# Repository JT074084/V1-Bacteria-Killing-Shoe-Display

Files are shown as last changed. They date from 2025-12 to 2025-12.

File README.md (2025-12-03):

# V1 Bacteria Killing Shoe Display

These are all the files for V1 of the Bacteria Killing Shoe Display.

Keep in mind, I had pieced together the main ESP32 code from bits of code that either I or an LLM had written in the past, so if anything looks off/messy, that's probably why.

I apologize for the lack of a schematic/wiring diagram for this. Unfortunately, I was figuring out where everything should go as I was programming it, and I didn't really write anything down.

In the video, I didn't really get into the specifics of how everything fit together, but if you do decide to build this, I have included a "problems and pictures" doc. This document has a list of the different problems that V1 has, along with pictures to help show how things fit together.

Now, if you don't want to build this but saw some sort of component you liked, I've also included a "materials list" doc, which has all of the different parts I used, along with links to where you can get them.

Anyway, thank you for watching the video! I hope you enjoyed it! I have some ideas for a V2 that should be way cooler than this, but we'll have to see what happens next.

## Licenses

| Content | License | What This Means |
|---|---|---|
| **Code** (`V1_Shoe_Display.ino`, `debug_ui.py`) | **[MIT License](LICENSE)** | Free to use, modify, sell — just keep my copyright |
| **3D Models** (`.stl`) | **[CC BY-SA 4.0](LICENSE-3D.txt)** | Free to print, remix, sell — **must credit me** + share remixes under same license |
| **PDF Docs** (`*.pdf`) | Same as **3D models** → **CC BY-SA 4.0** | Diagrams, photos, and text are part of the design |

**Copyright © 2025 JT074084**

*JT074084*

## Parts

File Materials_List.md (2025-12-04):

V1 Shoe Display Materials List:
JLCMC Parts
Linear Actuator: https://jlcmc.com/product/s/B16/BQD-JKK60B/steel-linear-actuators-kk-series-motor-side-installation-60mm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 | Part Number: JKK60B-5-P-300-A2-LM-L-57-C 
Cooling and Chlorine Dioxide Fans: https://jlcmc.com/product/b/I08/BR5690/fa-%E5%B7%A5%E4%B8%9A%E6%8E%A7%E5%88%B6-%E4%BD%8E%E5%8E%8B%E9%85%8D%E7%94%B5-%E7%94%B5%E6%B0%94%E8%BE%85%E6%9D%90-%E9%A3%8E%E6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 | Part Number: INAF-80
Drag Chain End Links: https://jlcmc.com/product/s/B11/BKTJ/fa-%E7%9B%B4%E7%BA%BF%E8%BF%90%E5%8A%A8%E9%9B%B6%E4%BB%B6-%E6%8B%96%E9%93%BE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 | Part Number: BKTJ-F20
Drag Chain Middle Links: https://jlcmc.com/product/s/B11/BKLJ/cable-carrier-15-series-bridge-type-non-openable | Part Number: BKLJ-F20-R28-N30-BKTJ 
DRAG CHAIN NOTE: When I bought the drag chain for this project, I accidentally only selected the end links. To avoid the delivery wait, I actually ended up 3d printing the middle ones (I have the files for that in my STL files folder), but I noticed the 3d printed ones were pretty weak. So I found the middle links on JLCMC, and I recommend you use those. They’ll be of much higher quality than standard FDM printed ones.
2020A Aluminium Rail: https://jlcmc.com/product/s/T01/TXCJ/extruded-aluminum-t-slot-20-series(eu) | Part Number: TXCJ-H6-2020A-L200 (Note: You would need around 152mm of this stuff for the connection areas, but 200mm should definitely cover miscuts and stuff.)
2040 Aluminium Rail: https://jlcmc.com/product/s/T01/TXCJ/extruded-aluminum-t-slot-20-series(eu) | Part Number: TXCJ-H7-2040-L400 (Note: You need around 348mm of this for the shoe bed, but this should give you an extra 50mm.)
ALUMINIUM RAIL NOTE: I originally got my rail off of an old Ender 3 3D printer I had, but these should be the same size.

Other Parts
PETG | Main Print Material: https://a.co/d/eFtnlSz (Note: I think it took around four 1kg rolls to make this.)
PETG | Door Print Material: https://a.co/d/3wo1hnw  (Note: I think it took one 1kg roll to make the shell for the door.)
TPU | Spring Material: https://a.co/d/5l1x0uM 
Power Supply: https://a.co/d/cfOMF5U 
Power Cable for Power Supply: https://a.co/d/dL7Kbja  
On/Off Switch Module for Power Supply: https://a.co/d/ajjtZjK  
Buck Converters: https://a.co/d/91aooBY  
Breadboards: https://a.co/d/bN8AEsD  
ESP-32: https://a.co/d/5vCUf5K  
Resistors: https://a.co/d/iCSJfpk  
Diodes: https://a.co/d/8zumlme 
Display RGB LEDs: https://a.co/d/b015BdR 
Buttons: https://a.co/d/9Ch9rfy 
Bearings: https://a.co/d/3fU0wwJ 
Servo: https://a.co/d/btITpLg
Stepper Motor: https://a.co/d/cRLKZDN 
Stepper Motor Driver: https://a.co/d/aeNL8AM 
Copper Tape: https://a.co/d/1QdixYN 
Glue: https://a.co/d/4SLxNcS 
Spiral Cable Wrap: https://a.co/d/axzYKvL (Note: I didn’t get mine off of Amazon, and I can’t remember the size, but it looks to be around ⅛”, so I hope this works.)
24 Gauge Wire: https://a.co/d/i1DXdUt 
Limit Switches: https://a.co/d/89OjKXr 
Easy Wire Connectors: https://a.co/d/7c76Mut (Note: These are supposed to be for cars or boats, but I found they worked pretty great for connecting things that needed to be disconnected often, like the fans.)
Sponges for Chlorine Dioxide: https://www.homedepot.com/p/HDX-All-Purpose-Easy-Eraser-Sponge-6-Sponges-HDX-6pk-Orig/307833221 
Chlorine Dioxide Tablets: https://a.co/d/70uV1f7 (Note: Be careful with these! I had the solution set out in the open for a few days before I put it in the shoe display.)
Carbon Fiber Rods: https://a.co/d/fpbQZGR 
UVC LEDs: https://www.lcsc.com/product-detail/C688875.html

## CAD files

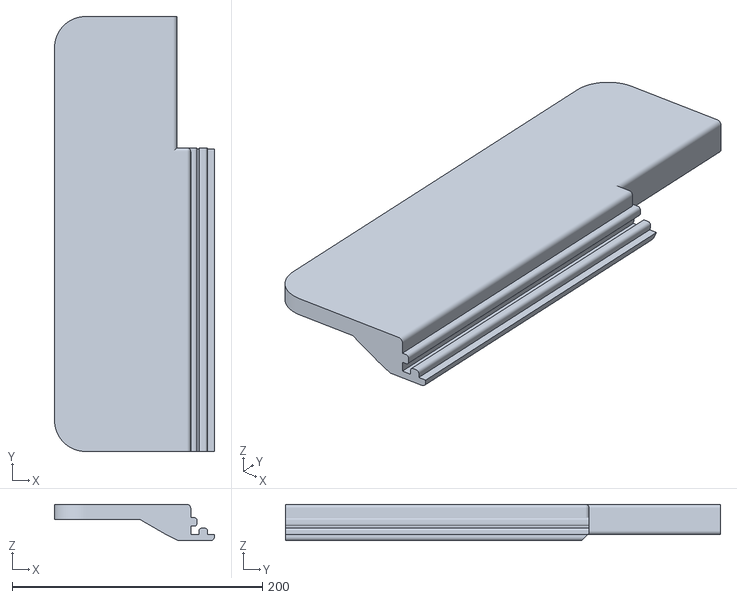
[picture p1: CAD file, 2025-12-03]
STL FILES/Shoe Bed Stuff/Bed Parts/V1 FINAL - Left Bed - Main.stl
128.0 x 348.0 x 29.0

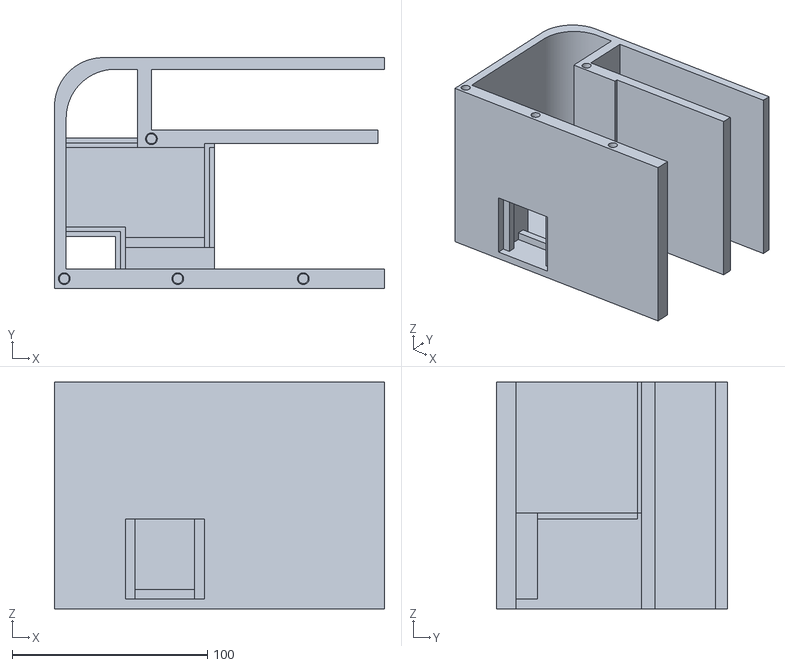
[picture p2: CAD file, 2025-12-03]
STL FILES/Base Stuff/Left Side Top Half/Left Side Main.stl
168.9 x 118.1 x 116.0

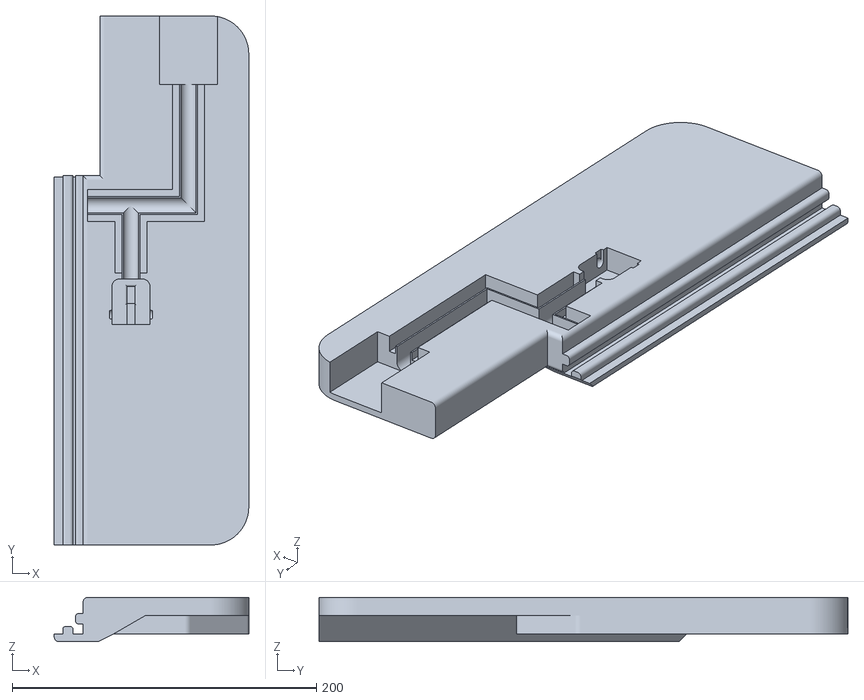
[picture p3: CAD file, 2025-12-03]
STL FILES/Shoe Bed Stuff/Bed Parts/V1 FINAL - Right Bed - Main.stl
128.0 x 348.0 x 29.0

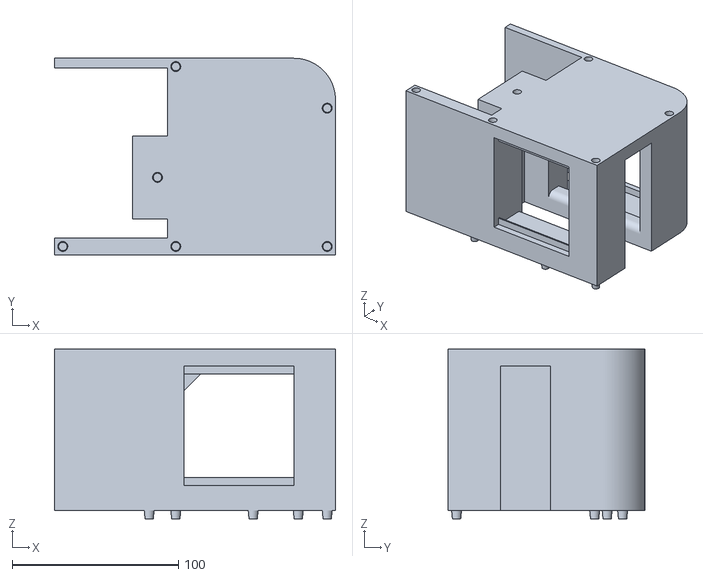
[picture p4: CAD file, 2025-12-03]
STL FILES/Base Stuff/Push Latch Mechanism Side/PLM Middle Main.stl
168.9 x 118.1 x 102.0

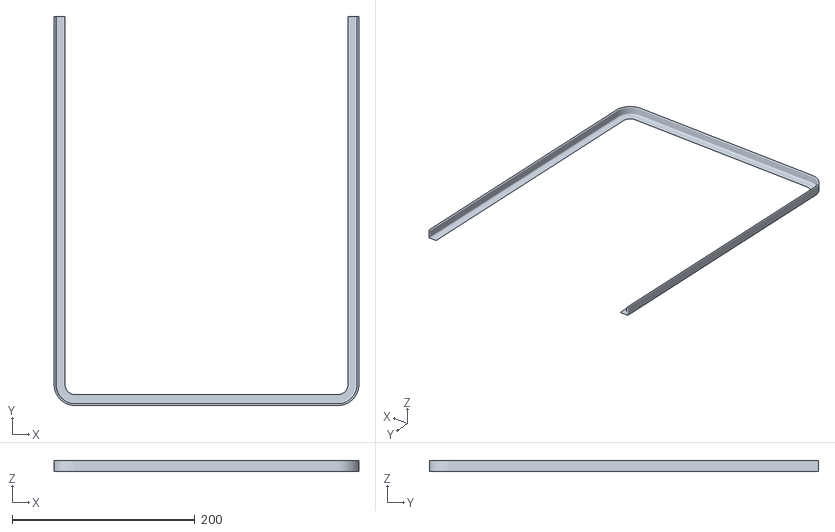
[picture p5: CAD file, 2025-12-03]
STL FILES/Base Stuff/LED Bar and Base Covers/V1 FINAL - LED Disperser.stl
333.8 x 426.0 x 12.0

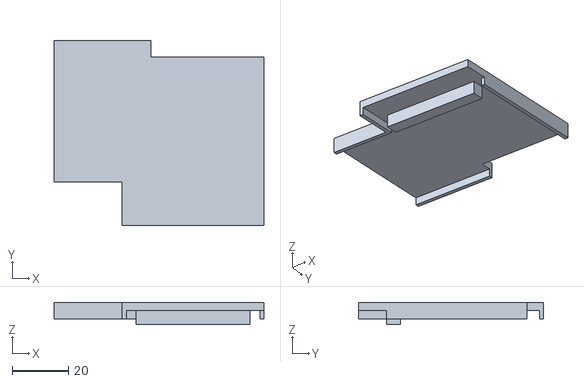
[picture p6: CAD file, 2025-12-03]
STL FILES/Base Stuff/Left Side Top Half/Left Side Air Duct Roof.stl
74.8 x 66.0 x 8.00

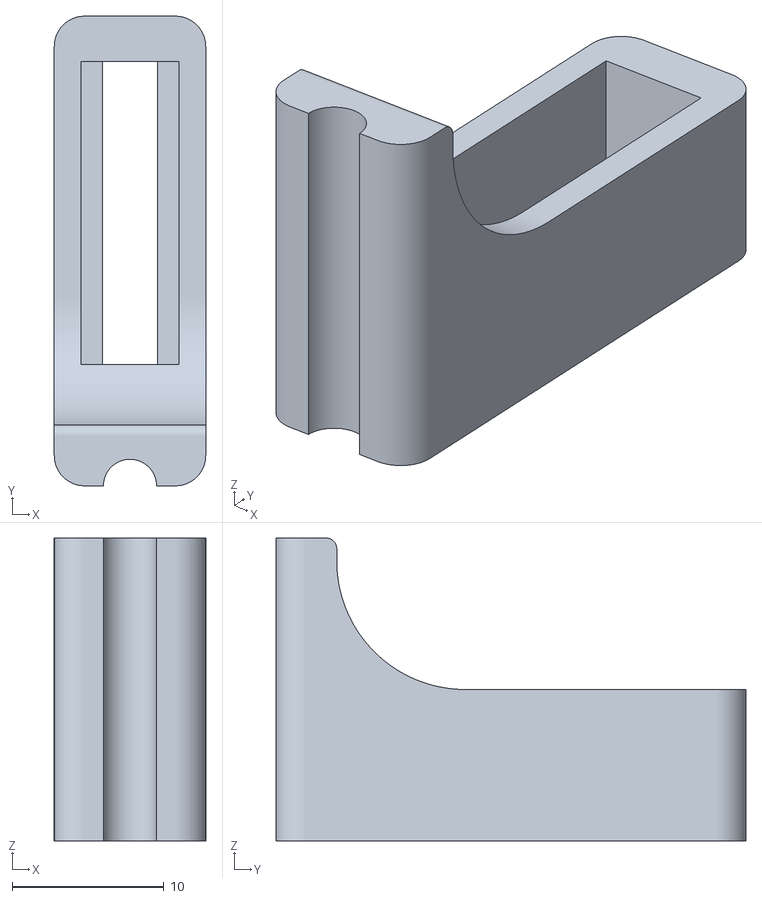
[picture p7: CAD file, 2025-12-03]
STL FILES/Base Stuff/Linear Actuator Stuff/Limit Switches/Limit Switch Case.stl
10.0 x 31.0 x 20.0

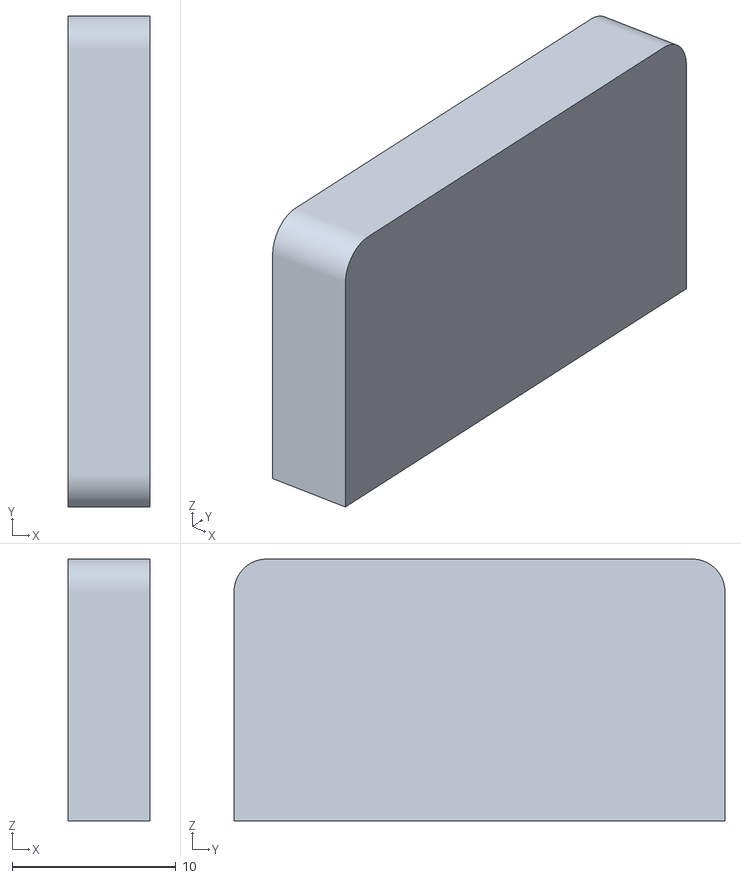
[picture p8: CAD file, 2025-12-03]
STL FILES/Base Stuff/Linear Actuator Stuff/Spacers/V1 FINAL - LAS 7.stl
5.00 x 30.0 x 16.0

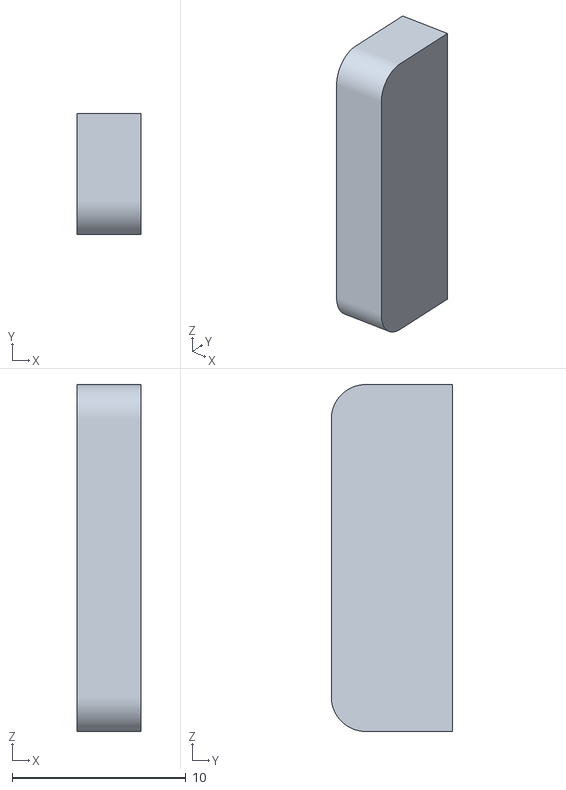
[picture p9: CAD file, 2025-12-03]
STL FILES/Base Stuff/Open:Close Button Stuff/V1 FINAL - Left Button Rail Cover.stl
3.70 x 7.00 x 20.0

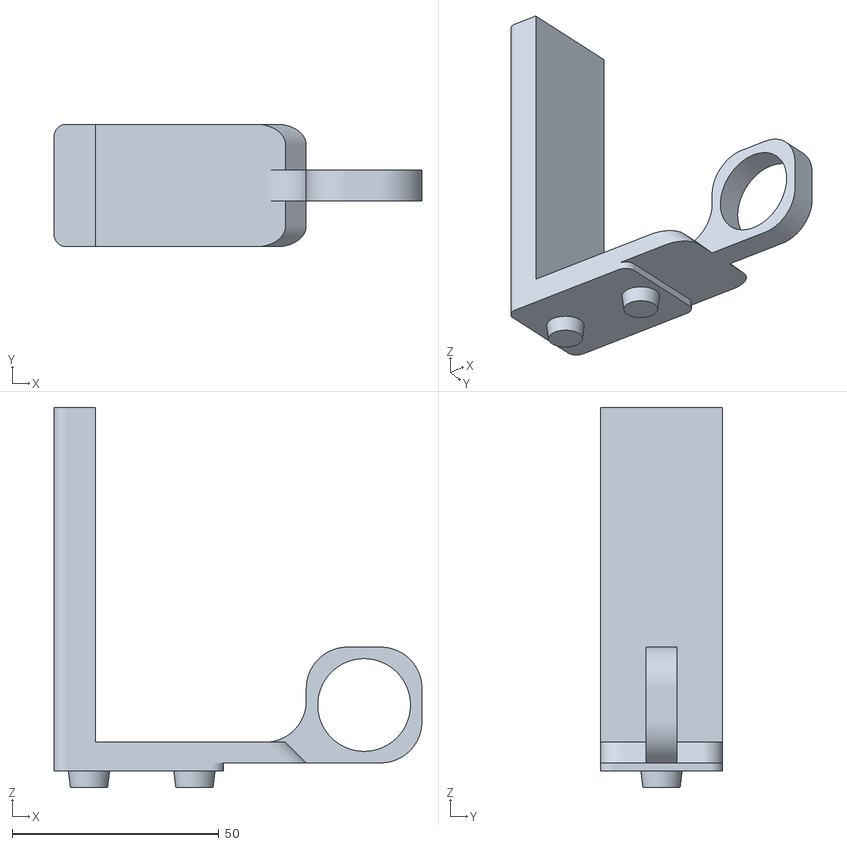
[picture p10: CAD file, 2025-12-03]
STL FILES/Base Stuff/Push Latch Mechanism Side/PLM Container Shelf.stl
89.0 x 29.6 x 92.0

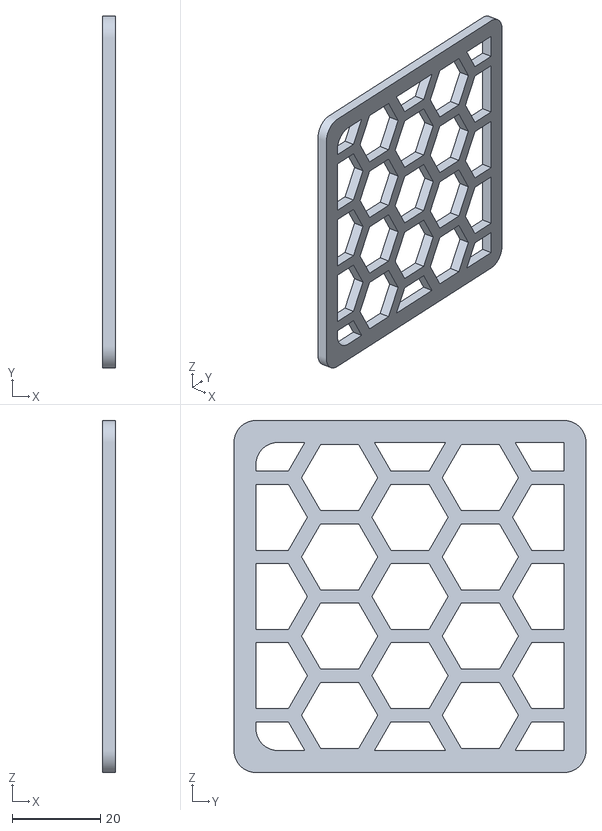
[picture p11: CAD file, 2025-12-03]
STL FILES/Base Stuff/V1 FINAL - Electronics Cooling Fan Guard.stl
3.00 x 80.0 x 80.0

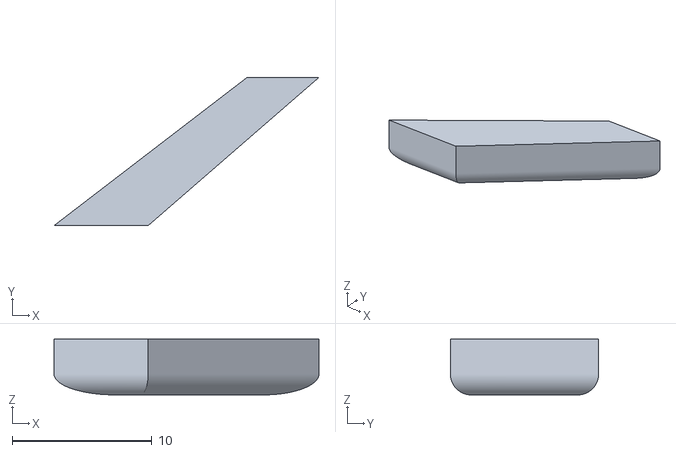
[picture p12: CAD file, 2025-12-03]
STL FILES/Door Stuff/Door Arm Stuff/Arm Connecting Pieces/Logo/V1 FINAL - Logo 4.stl
19.0 x 10.6 x 4.00

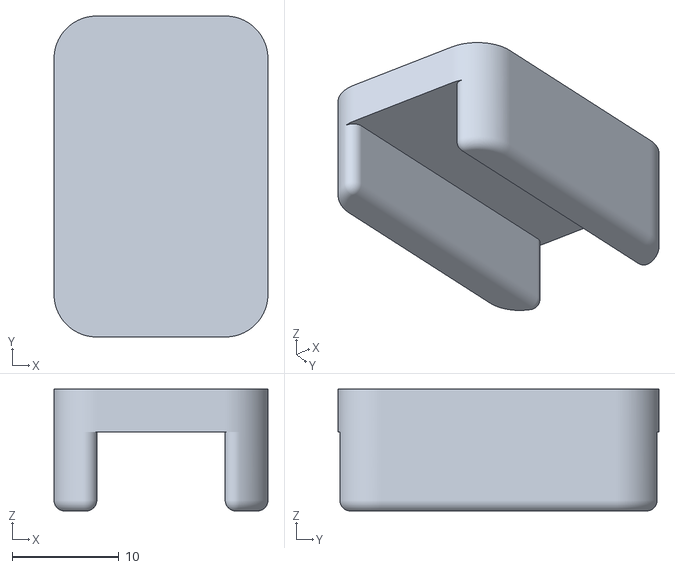
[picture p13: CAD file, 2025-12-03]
STL FILES/Door Stuff/Door Arm Stuff/Arm Connecting Pieces/V1 FINAL - ARM LT.stl
20.0 x 30.0 x 11.4

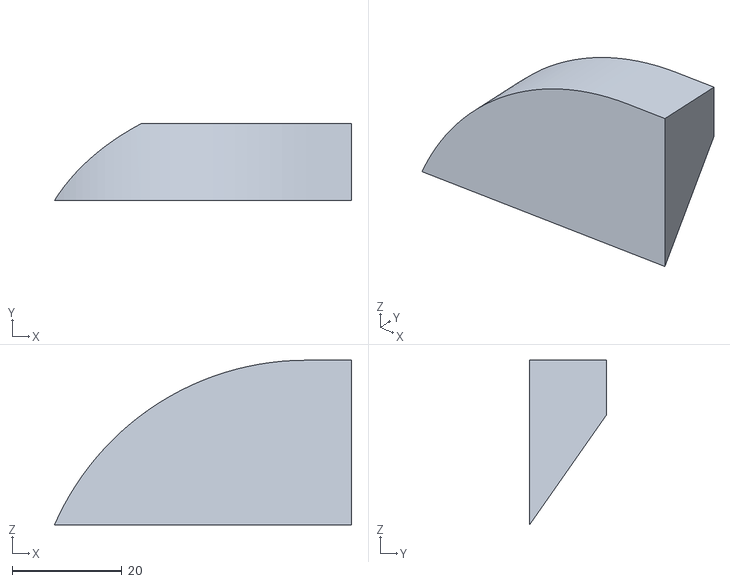
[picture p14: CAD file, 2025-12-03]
STL FILES/Door Stuff/Door Arm Stuff/V1 FINAL - Bearing Case Spacer Left.stl
54.1 x 14.0 x 30.0

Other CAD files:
STL FILES/Door Stuff/V1 FINAL - Door.stl
STL FILES/Shoe Bed Stuff/Bed Parts/V1 FINAL - Left Bed - Back.stl
STL FILES/Shoe Bed Stuff/Drag Chain/Wire Chain Bed Connect V1.stl
STL FILES/Shoe Bed Stuff/Logo Cap/V1 FINAL - BPL 2.stl
STL FILES/Base Stuff/LED Bar and Base Covers/V1 FINAL - Base Cap.stl
STL FILES/Base Stuff/LED Bar and Base Covers/V1 FINAL - Side LED Attachment.stl
STL FILES/Base Stuff/Left Side Top Half/Left Side Top Half Cap.stl
STL FILES/Base Stuff/Left Side Top Half/Left Side Top Half Inside Fan Guard.stl
STL FILES/Base Stuff/Left Side Top Half/Left Side Top Half Outside Fan Guard.stl
STL FILES/Base Stuff/Left Side Top Half/Servo Area Cap.stl
STL FILES/Base Stuff/Linear Actuator Stuff/Spacers/V1 FINAL - LAS 1.stl
STL FILES/Base Stuff/Linear Actuator Stuff/Spacers/V1 FINAL - LAS 4.stl
STL FILES/Base Stuff/Linear Actuator Stuff/Spacers/V1 FINAL - LAS 5.stl
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

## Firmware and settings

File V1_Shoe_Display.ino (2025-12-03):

#include <ESP32Servo.h>
#include <WiFi.h>
#include <WebServer.h>
#include <ArduinoOTA.h>
#include <AccelStepper.h>
#include <NeoPixelBus.h>

// WiFi
const char *ssid = "YOUR_SSID_HERE";
const char *password = "YOUR_PASSWORD_HERE";

const int LED = 2;

WebServer server(80);

// Servo
const int servoPin = 13;

Servo largeServo;

int currentAngle = 45;
int targetAngle = 0;

// LA Bed
const int pulPin = 23;
const int dirPin = 14;
const int enablePin = 27;

AccelStepper bedStepper(AccelStepper::DRIVER, pulPin, dirPin);

const int limitOutside = 19;
const int limitInside = 16;

// Fans
const int insideFan = 25;
const int outsideFan = 21;

// Display LEDs
const uint16_t TotalLeds = 68;
const uint16_t ActiveLeds = 68;
const uint8_t DataPin = 5;

NeoPixelBus<NeoGrbFeature, NeoEsp32Rmt0Ws2812xMethod> strip(TotalLeds, DataPin);

// UVC LEDS
const int uvcLEDs = 26;

// Shoe Sensor
const int shoeSensor = 18;

// Color State Enum
enum class ColorState { RED, GREEN, WHITE, YELLOW, NONE }; // This is basically a list, with each color having a number, like white == 0.
volatile ColorState mainColor = ColorState::NONE; // Shared variable 

// Mutex for critical sections
portMUX_TYPE mux = portMUX_INITIALIZER_UNLOCKED; // This is like making a room and setting the door to unlocked so only one task at a time can enter and change stuff

// Universal Button
const int button = 32;

// == GLOBAL VARIABLE
volatile bool disinfectTaskActive = false;
volatile bool disinfectTaskComplete = false;

// Task Handles
// == DEBUG TASK HANDLES ==
volatile bool debugMode = false; 
TaskHandle_t debugTaskHandle = NULL;
// == NORMAL OP TASK HANDLES ==
// Subtasks
TaskHandle_t ledSwitcherTaskHandle = NULL;
TaskHandle_t disinfectingTaskHandle = NULL;
TaskHandle_t electronicsCoolingTaskHandle = NULL;
// Main Normal Task
TaskHandle_t normalTaskHandle = NULL;
// == SWITCHER TASK HANDLES ==
TaskHandle_t switcherTaskHandle = NULL;

// == TASK FUNCTION ==
// Switcher Task
void switcherTask(void *parameter) {
  bool lastButtonState = HIGH;
  bool buttonState = HIGH;
  unsigned long pressStartTime = 0;
  bool hasSwitched = false;

  for (;;) {
    buttonState = digitalRead(button);

    if (lastButtonState == HIGH && buttonState == LOW) {
      pressStartTime = millis();
      hasSwitched = false;
    }

    if (buttonState == LOW && !hasSwitched && (millis() - pressStartTime >= 5000)) {
      debugMode = !debugMode;
      hasSwitched = true;
      pressStartTime = millis() + 60000;
      if (debugMode) {
        // Delete Subtasks
        if (ledSwitcherTaskHandle != NULL) {
          vTaskDelete(ledSwitcherTaskHandle);
          ledSwitcherTaskHandle = NULL;
        }
        if (electronicsCoolingTaskHandle != NULL) {
          // Turn off Fan
          coolingFanOff();
          vTaskDelete(electronicsCoolingTaskHandle);
          electronicsCoolingTaskHandle = NULL;
        }
        if (disinfectingTaskHandle != NULL) {
          vTaskDelete(disinfectingTaskHandle);
          disinfectingTaskHandle = NULL;
        }
        // Delete Main Tasks
        if (normalTaskHandle != NULL) {
          vTaskDelete(normalTaskHandle);
          normalTaskHandle = NULL;
        }
        xTaskCreatePinnedToCore(
          debugTask,
          "Debug Task",
          10000,
          NULL,
          5,
          &debugTaskHandle,
          1
        );
      } else {
        if (debugTaskHandle != NULL) {
          vTaskDelete(debugTaskHandle);
          debugTaskHandle = NULL;
        }
        xTaskCreatePinnedToCore(
          normalTask,
          "Normal Task",
          10000,
          NULL,
          5,
          &normalTaskHandle,
          1
        );
      }
    }

    lastButtonState = buttonState;
    vTaskDelay(50 / portTICK_PERIOD_MS);  // Add 50ms delay for debouncing
  }; 
}


// == NORMAL OPERATIONS TASKS
// SUBTASKS
// LED Controls Task
void ledSwitchTask(void *parameter) {
  int lightLevel = 0;
  const int unit = 2.55;
  const int levels = 100;
  const int time = 10;
  
  for (;;) {
    ColorState currentColor; // This just creates a local variable for the ColorState class
    // Safely read mainColor
    portENTER_CRITICAL(&mux);
    currentColor = mainColor;
    portEXIT_CRITICAL(&mux);

    // RED
    if (currentColor == ColorState::RED) {
      for (int a = 0; a < levels; a++) {
        for (uint16_t i = 0; i < TotalLeds; i++) {
          strip.SetPixelColor(i, RgbColor(lightLevel,0,0));
        }
        strip.Show();
        lightLevel += unit;
        vTaskDelay(time / portTICK_PERIOD_MS);
      }
      for (int a = 0; a < levels; a++) {
        for (uint16_t i = 0; i < TotalLeds; i++) {
          strip.SetPixelColor(i, RgbColor(lightLevel,0,0));
        }
        strip.Show();
        lightLevel -= unit;
        vTaskDelay(time / portTICK_PERIOD_MS);
      }
    // GREEN
    } else if (currentColor == ColorState::GREEN) {
      for (int a = 0; a < levels; a++) {
        for (uint16_t i = 0; i < TotalLeds; i++) {
          strip.SetPixelColor(i, RgbColor(0,lightLevel,0));
        }
        strip.Show();
        lightLevel += unit;
        vTaskDelay(time / portTICK_PERIOD_MS);
      }
      for (int a = 0; a < levels; a++) {
        for (uint16_t i = 0; i < TotalLeds; i++) {
          strip.SetPixelColor(i, RgbColor(0,lightLevel,0));
        }
        strip.Show();
        lightLevel -= unit;
        vTaskDelay(time / portTICK_PERIOD_MS);
      }
    // WHITE
    } else if (currentColor == ColorState::WHITE) {
      for (int a = 0; a < levels; a++) {
        for (uint16_t i = 0; i < TotalLeds; i++) {
          strip.SetPixelColor(i, RgbColor(lightLevel,lightLevel,lightLevel));
        }
        strip.Show();
        lightLevel += unit;
        vTaskDelay(time / portTICK_PERIOD_MS);
      }
      for (int a = 0; a < levels; a++) {
        for (uint16_t i = 0; i < TotalLeds; i++) {
          strip.SetPixelColor(i, RgbColor(lightLevel,lightLevel,lightLevel));
        }
        strip.Show();
        lightLevel -= unit;
        vTaskDelay(time / portTICK_PERIOD_MS);
      }
    // YELLOW
    } else if (currentColor == ColorState::YELLOW) {
      for (int a = 0; a < levels; a++) {
        for (uint16_t i = 0; i < TotalLeds; i++) {
          strip.SetPixelColor(i, RgbColor(lightLevel,lightLevel,0));
        }
        strip.Show();
        lightLevel += unit;
        vTaskDelay(time / portTICK_PERIOD_MS);
      }
      for (int a = 0; a < levels; a++) {
        for (uint16_t i = 0; i < TotalLeds; i++) {
          strip.SetPixelColor(i, RgbColor(lightLevel,lightLevel,0));
        }
        strip.Show();
        lightLevel -= unit;
        vTaskDelay(time / portTICK_PERIOD_MS);
      }
    }
  }
}
// Electronics Cooling Task
void electronicsCoolingTask(void *parameter) {
  for (;;) {
    vTaskDelay(600000 / portTICK_PERIOD_MS);
    coolingFanOn();
    vTaskDelay(300000 / portTICK_PERIOD_MS);
    coolingFanOff();
  }
}
// Disinfecting Task
void disinfectingTask(void *parameter) {
  // Sequence Test
  // Switch LED Color
  portENTER_CRITICAL(&mux);
  mainColor = ColorState::YELLOW;
  portEXIT_CRITICAL(&mux);

  // Actual Disinfecting Stuff
  chamberFanOn();
  for (int i = 0; i < 10; i++) {
    uvcOn();
    vTaskDelay(60000 / portTICK_PERIOD_MS);
    uvcOff();
    vTaskDelay(180000 / portTICK_PERIOD_MS);
  }
  vTaskDelay(1200000 / portTICK_PERIOD_MS);
  chamberFanOff();

  // == END OF DISINFECTING TASK ==
  // Set Disinfect Task to Unactive
  disinfectTaskActive = false;
  // Set task complete to true
  disinfectTaskComplete = true;

  // Delete Task
  if (disinfectingTaskHandle != NULL) {
    vTaskDelete(disinfectingTaskHandle);
    disinfectingTaskHandle = NULL;
  }
}
// MAIN NORMAL TASK
void normalTask(void *parameter) {
  // Setup
  // Create LED Task
  xTaskCreatePinnedToCore(
    ledSwitchTask,
    "Led Switcher Task",
    10000,
    NULL,
    5,
    &ledSwitcherTaskHandle,
    0
  );
  // Create Cooling Fan Task
  xTaskCreatePinnedToCore(
    electronicsCoolingTask,
    "Electronics Colling Task",
    10000,
    NULL,
    10,
    &electronicsCoolingTaskHandle,
    0
  );

  // Button press detection
  unsigned long pressStartTime = 0;
  bool buttonPressed = false;
  const unsigned long longPressTime = 5000;
  unsigned long buttonDuration = 0;

  bool doorOpened = false;

  bool phaseActive = false;

  // Door Open Timing
  unsigned long openTime = 0;
  const unsigned long closeLimit = 30000;

  // Shoe In Bay Check
  bool shoeInBay = false;

  bool noShoe = false;


  // Loop
  for (;;) {
    unsigned long currentTime = millis();

    // Auto Close
    if (doorOpened && (currentTime - openTime > closeLimit)) {
      // Change Color
      portENTER_CRITICAL(&mux);
      mainColor = ColorState::RED;
      portEXIT_CRITICAL(&mux);
      slideInBed();
      closeDoor();
      doorOpened = false;
      Serial.println("Auto-closed after timeout");
    }

    int buttonState = digitalRead(button);

    // Capture First Inital Press
    if (buttonState == LOW && !buttonPressed) {
      buttonPressed = true;
      pressStartTime = currentTime;
    }

    // See how long the press is
    if (buttonState == HIGH && buttonPressed) {
      buttonDuration = currentTime - pressStartTime;
      buttonPressed = false;

      // if the press is a short one, then we'll either open or close the doors
      if (buttonDuration < longPressTime) {  // Short press
        if (!doorOpened) {
          // First check to see if a disinfecting task was active and if so delete it
          if (disinfectTaskActive && disinfectingTaskHandle != NULL) {
            disinfectTaskActive = false;
            vTaskDelete(disinfectingTaskHandle);
            disinfectingTaskHandle = NULL;
            // Turn of LEDs and FANS
            uvcOff();
            chamberFanOff();
          }
          noShoe = false;
          disinfectTaskComplete = false;
          // Open sequence
          portENTER_CRITICAL(&mux);
          mainColor = ColorState::GREEN;
          portEXIT_CRITICAL(&mux);
          openDoor();
          slideOutBed();
          doorOpened = true;
          openTime = currentTime;
          Serial.println("Opened on short press");
        } else {
          // Close sequence
          portENTER_CRITICAL(&mux);
          mainColor = ColorState::RED;
          portEXIT_CRITICAL(&mux);
          slideInBed();
          closeDoor();
          doorOpened = false;
          Serial.println("Closed on short press");
        }
      } else {
        Serial.println("Entering Debug Mode (long press)");
      }

      buttonDuration = 0;  // Reset for next use
    }
    // Shoe Sensor Test
    if (digitalRead(shoeSensor) == LOW && !doorOpened && !disinfectTaskActive && !disinfectTaskComplete) {
      // Set Disinfect Task to Active
      disinfectTaskActive = true;
      // Setup Disinfecting Task
      xTaskCreatePinnedToCore(
        disinfectingTask,
        "Shoe Disinfecting Task",
        10000,
        NULL,
        20,
        &disinfectingTaskHandle,
        1
      );
    } else if (digitalRead(shoeSensor) == LOW && !doorOpened && !disinfectTaskActive && disinfectTaskComplete) {
      // Change Light Color to White
      portENTER_CRITICAL(&mux);
      mainColor = ColorState::WHITE;
      portEXIT_CRITICAL(&mux);
      // Reset Task Complete
      //disinfectTaskComplete = false;
    }

    // If no shoe is in the bay after closing then switch the LED color back to white
    if (digitalRead(shoeSensor) == HIGH && noShoe == false && !doorOpened) {
      portENTER_CRITICAL(&mux);
      mainColor = ColorState::WHITE;
      portEXIT_CRITICAL(&mux);
      noShoe = true;
    }
  }
}
// Debug Task
void debugTask(void *parameter) {
  // == HTTP REQUEST SETUP ==
  server.on("/doorOpen", debugOpenDoor);
  server.on("/doorClose", debugCloseDoor);
  server.on("/bedSlideIn", debugSlideInBed);
  server.on("/bedSlideOut", debugSlideOutBed);
  server.on("/chamberFanOn", debugChamberFanOn);
  server.on("/chamberFanOff", debugChamberFanOff);
  server.on("/coolingFanOn", debugCoolingFanOn);
  server.on("/coolingFanOff", debugCoolingFanOff);
  server.on("/uvcLEDsOn", debugUvcOn);
  server.on("/uvcLEDsOff", debugUvcOff);
  server.begin();

  // LED Update
  for (uint16_t i = 0; i < TotalLeds; i++) {
    strip.SetPixelColor(i, RgbColor(50,50,255));
    strip.Show();
    vTaskDelay(25 / portTICK_PERIOD_MS);
  }

  // Loop
  for (;;) {
    // Must Haves
    server.handleClient();
    ArduinoOTA.handle();
  }
}

// == FUNCTIONS == 
// == DOOR CONTROLS ==
// Debug Open Door
void debugOpenDoor() {
  openDoor();
  server.send(200, "text/plain", "Door is open");
}
// Open Servo Door
void openDoor() {
  targetAngle = 0;
  while (currentAngle > targetAngle) {
    currentAngle--;
    largeServo.write(currentAngle);
    vTaskDelay(20 / portTICK_PERIOD_MS);
  }
}

// Debug Close Door
void debugCloseDoor() {
  closeDoor();
  server.send(200, "text/plain", "Door is closed");
}
// Close Servo Door
void closeDoor() {
  targetAngle = 45;
  while (currentAngle < targetAngle) {
    currentAngle++;
    largeServo.write(currentAngle);
    vTaskDelay(30 / portTICK_PERIOD_MS);
  }
}

// == BED CONTROLS ==
// Debug Slide Bed In
void debugSlideInBed() {
  slideInBed();
  server.send(200, "text/plain", "The Bed Has Slid In");
}
// Slide Bed In
void slideInBed() {
  digitalWrite(enablePin, LOW); // Turn On Driver
  bool limitHit = false;
  // Set Direction
  long moveDistance = 179081;
  bedStepper.move(moveDistance);

  // Move until the limit switch is pressed
  while (bedStepper.distanceToGo() != 0 && !limitHit) {
    bedStepper.run();
    if (digitalRead(limitInside) == LOW) {
      limitHit = true;
    }
    taskYIELD();
  }

  if (limitHit) {
    digitalWrite(enablePin, HIGH); // Emergency Stop
  }
  bedStepper.setCurrentPosition(0);
}

// Debug Slide Bed Out
void debugSlideOutBed() {
  slideOutBed();
  server.send(200, "text/plain", "The Bed Has Slid Out");
}
// Slide Bed Out
void slideOutBed() {
  digitalWrite(enablePin, LOW); // Turn On Driver
  bool limitHit = false;
  // Set Direction
  long moveDistance = -179081;
  bedStepper.move(moveDistance);

  // Move until the limit switch is pressed
  while (bedStepper.distanceToGo() != 0 && !limitHit) {
    bedStepper.run();
    if (digitalRead(limitOutside) == LOW) {
      limitHit = true;
    }
    taskYIELD();
  }
  
  if (limitHit) {
    digitalWrite(enablePin, HIGH); // Emergency Stop
  }
  bedStepper.setCurrentPosition(0);
}

// == FAN CONTROLS ==
// Chamber Fan
// Debug Chamber Fan On
void debugChamberFanOn() {
  chamberFanOn();
  server.send(200, "text/plain", "Chamber Fan is On");
}
// Chamber Fan On
void chamberFanOn() {
  digitalWrite(insideFan, HIGH);
}
// Debug Chamber Fan Off
void debugChamberFanOff() {
  chamberFanOff();
  server.send(200, "text/plain", "Chamber Fan if Off");
}
// Chamber Fan Off
void chamberFanOff() {
  digitalWrite(insideFan, LOW);
}

// Cooling Fan
// Debug Cooling Fan On
void debugCoolingFanOn() {
  coolingFanOn();
  server.send(200, "text/plain", "Cooling Fan is On");
}
// Cooling Fan On
void coolingFanOn() {
  digitalWrite(outsideFan, HIGH);
}
// Debug Cooling Fan Off
void debugCoolingFanOff() {
  coolingFanOff();
  server.send(200, "text/plain", "Cooling Fan is Off");
}
// Cooling Fan Off
void coolingFanOff() {
  digitalWrite(outsideFan, LOW);
}

// UVC LEDs
// Debug UVC LEDs On
void debugUvcOn() {
  uvcOn();
  server.send(200, "text/plin", "The UVC LEDs Are On");
}
// UVC LEDs On
void uvcOn() {
  digitalWrite(uvcLEDs, HIGH);
}

// Debug UVC LEDs Off
void debugUvcOff() {
  uvcOff();
  server.send(200, "text/plain", "The UVC LEDs Are Off");
}
// UVC LEDs Off
void uvcOff() {
  digitalWrite(uvcLEDs, LOW);
}

// == SETUP ==
void setup() {
  Serial.begin(115200);
  // == PIN MODES ==
  pinMode(LED, OUTPUT);
  pinMode(servoPin, OUTPUT);
  pinMode(enablePin, OUTPUT);
  pinMode(limitOutside, INPUT_PULLUP);
  pinMode(limitInside, INPUT_PULLUP);
  pinMode(button, INPUT_PULLUP);
  pinMode(insideFan, OUTPUT);
  pinMode(outsideFan, OUTPUT);
  pinMode(uvcLEDs, OUTPUT);
  pinMode(shoeSensor, INPUT_PULLUP);

  // UVC LEDs
  digitalWrite(uvcLEDs, LOW);

  // FAN TESTING
  digitalWrite(insideFan, LOW);
  digitalWrite(outsideFan, LOW);

  // == SERVO SETUP ==
  largeServo.attach(servoPin);
  largeServo.write(currentAngle);

  // == WIFI SETUP ==
  WiFi.mode(WIFI_STA);
  WiFi.begin(ssid, password);
  while (WiFi.waitForConnectResult() != WL_CONNECTED) {
    Serial.println("Connection Failed! Rebooting...");
    delay(5000);
    ESP.restart();
  }

  // == OTA UPDATES SETUP ==
  // Setup OTA
  ArduinoOTA.onStart([]() {
    Serial.println("OTA: Start updating");
  });
  ArduinoOTA.onEnd([]() {
    Serial.println("\nOTA: End");
  });
  ArduinoOTA.onProgress([](unsigned int progress, unsigned int total) {
    Serial.printf("OTA Progress: %u%%\r", (progress / (total / 100)));
  });
  ArduinoOTA.onError([](ota_error_t error) {
    Serial.printf("OTA Error[%u]: ", error);
    if (error == OTA_AUTH_ERROR) Serial.println("Auth Failed");
    else if (error == OTA_BEGIN_ERROR) Serial.println("Begin Failed");
    else if (error == OTA_CONNECT_ERROR) Serial.println("Connect Failed");
    else if (error == OTA_RECEIVE_ERROR) Serial.println("Receive Failed");
    else if (error == OTA_END_ERROR) Serial.println("End Failed");
  });
  ArduinoOTA.begin();

  Serial.println("Ready");
  Serial.print("IP address: ");
  Serial.println(WiFi.localIP());

  // == LINEAR ACTUATOR SETUP
  // Set maximum speed and acceleration
  bedStepper.setMaxSpeed(40000.0);
  bedStepper.setAcceleration(40000.0); 
  digitalWrite(enablePin, HIGH); // Turn off driver to save power

  // == DISPLAY LED SETUP ==
  strip.Begin();
  strip.Show();
  portENTER_CRITICAL(&mux);
  mainColor = ColorState::WHITE;
  portEXIT_CRITICAL(&mux);

  // == INITIAL TASK SETUP ==
  // Switcher Task
  xTaskCreatePinnedToCore(
    switcherTask, // Function
    "Switcher Task", // Name
    10000, // Size
    NULL, // Parameters
    1, // Prority
    &switcherTaskHandle, // Task Handle
    0 // Core
  );
  // Normal Operations Task
  xTaskCreatePinnedToCore(
    normalTask,
    "Normal Task",
    10000,
    NULL,
    5,
    &normalTaskHandle,
    1
  );

  // LED Update Test
  digitalWrite(LED, HIGH);
  delay(1000);
  digitalWrite(LED, LOW);
}

void loop() {
}
